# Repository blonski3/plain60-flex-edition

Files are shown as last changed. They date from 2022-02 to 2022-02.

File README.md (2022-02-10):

# Plain60 MX+ALPS Flex Edition rev2.2

Plain60 Flex Edition PCB
This universal 60% PCB is designed to support as little layouts as possible without limiting usability for most users. The reason I did this is because other PCBs made for this form factor usually have so many supported layouts that it could almost qualify as swiss cheese.

It also features a fuse and an ESD protection chip to protect the MCU and other parts of the PCB.

## Features
- Fits in the TGR Unikorn
- Compatible with QMK Firmware and VIA Configurator (if you flash a VIA compatible .hex file)
- Compatible with most universal 60% cases and HHKB/WKL Tofu by KBDfans
- USB type-C
- Optional JST header for connection with daughterboard
- Footprint for optional speaker (AST1109MLTRQ)
- ESD protection and fuse
- No LEDs and no underglow
- Minimal layout support
- ISP header

## Supported layouts
Supported layouts of the Plain60-C

## Building
If you feel like building a few of these PCBs yourself, go to the 'Releases' tab and download the latest gerber files. Order those at your favourite PCB manufacturer, get the components needed (see below) and solder them on! A hot air station is not required but a soldering iron is. Flux is recommended.

## Opening the project
To open the files you will need the latest KiCAD nightly version.

## Bill of materials (BOM)
Amount is per PCB, multiply as needed.

| LCSC part # | Description | Value | Package  | Amount |
| --- | --- | ----- | --- | ---:|
| C128353 | Capacitor | 0.1uF | 0805 | 4 |
| C131056 | Capacitor | 4.7uF | 0805 | 1 |
| C215803 | Capacitor | 1uF | 0805 | 1 |
| C109001 | Diode | | 0805 | 65 |
| C261942 | Fuse | | 0805 | 1 |
| C165948 | Connector | | SMD/THT  | 1 |
| C103904 | Resistor | 10K | 0805 | 2 |
| C212411 | Resistor | 5.1K  | 0805 | 2 |
| C325772 | Resistor | 22 | 0805 | 2 |
| C44854 | MCU | 32U4  | QFP-44 | 1 |
| C7519 | ESD chip | | SOT23-6  | 1 |
| C341521 | Resonator | 16MHz | SMD | 1 |
| C92584 | Switch | | SMD | 1 |
| C160404 | Optional JST  | | SMD | 1 |

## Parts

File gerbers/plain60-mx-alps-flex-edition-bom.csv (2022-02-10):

Comment | Designator | Footprint | JLCPCB Part #（optional）
1u | C1 | C_0805 | C215803
0.1u | C4,C5,C2,C3 | C_0805 | C128353
4.7u | C6 | C_0805 | C131056
D | D73,D72,D71,D67,D63,D59,D58,D57,D56,D53,D51,D50,D27,D42,D18,D25,D41,D36,D31,D40,D37,D32,D34,D21,D26,D22,D24,D43,D38,D35,D48,D54,D44,D62,D39,D20,D28,D33,D23,D55,D52,D19,D10,D14,D9,D13,D11,D15,D17,D16,D12,D7,D3,D5,D8,D6,D4,D74,D49,D46,D29,D1,D47,D2,D61 | D_0805 | C109001
Polyfuse | F1 | R_0805 | C261942
HRO-TYPE-C-31-M-12 | J1 | HRO-TYPE-C-31-M-12 | C165948
ai03_ud | J3 | JST_SH_SM04B-SRSS-TB_1x04-1MP_P1.00mm_Horizontal | C160404
22 | R1,R2 | R_0805 | C413250
5.1k | R4,R3 | R_0805 | C212411
10k | R6,R5 | R_0805 | C103904
SW_PUSH | SW1 | SW_SPST_TL3342 | C92584
ATmega32U4 | U1 | ATMEGA32U4 | C44854
USBLC6-2SC6 | U2 | USBLC6-2SC6 | C7519
XTAL_GND | X1 | Resonator_SMD_muRata_CSTNExxV-3Pin-p1.2 | C341521

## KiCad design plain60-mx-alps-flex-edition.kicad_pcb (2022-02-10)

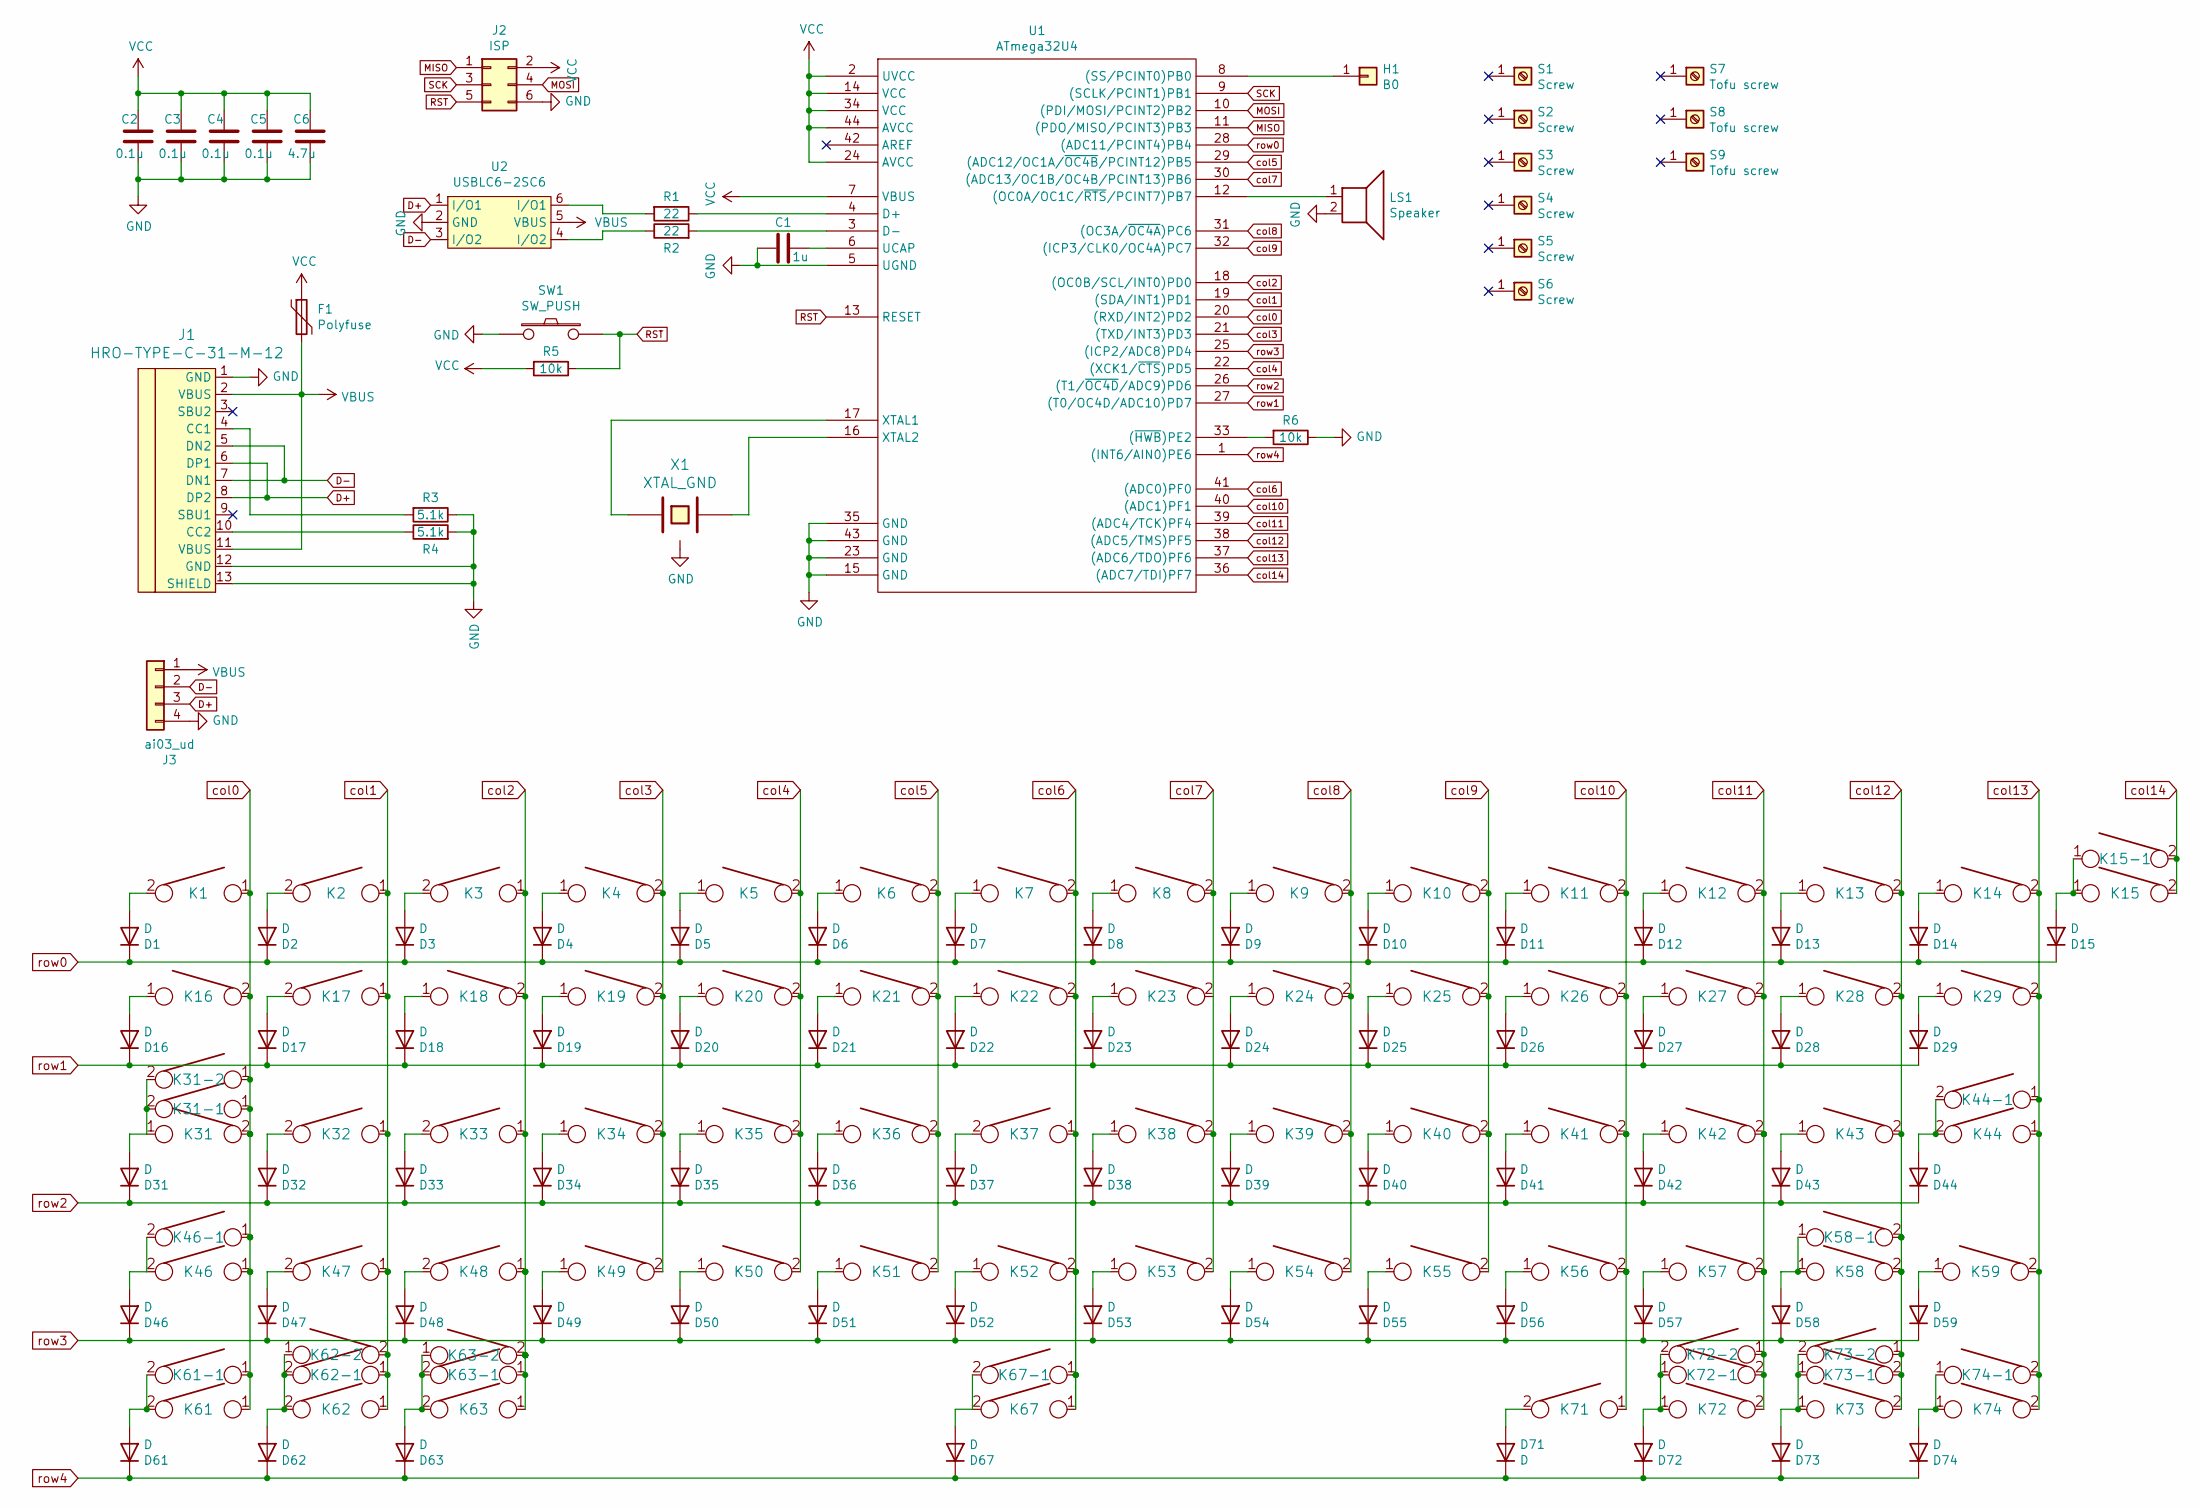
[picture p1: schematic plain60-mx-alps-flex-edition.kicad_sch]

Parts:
C1: 1u; C_0805
C2, C3, C4, C5: 0.1u; C_0805
C6: 4.7u; C_0805
D1, D2, D3, D4, D5, D6, D7, D8, D9, D10, D11, D12, D13, D14, D15, D16, D17, D18, D19, D20, D21, D22, D23, D24, D25, D26, D27, D28, D29, D31, D32, D33, D34, D35, D36, D37, D38, D39, D40, D41, D42, D43, D44, D46, D47, D48, D49, D50, D51, D52, D53, D54, D55, D56, D57, D58, D59, D61, D62, D63, D67, D71, D72, D73, D74: D; D_0805
F1: Polyfuse; R_0805
H1: B0; free_pin
J1: HRO-TYPE-C-31-M-12
J2: ISP; isp_standard
J3: ai03_ud; JST_SH_SM04B-SRSS-TB_1x04-1MP_P1.00mm_Horizontal
K1, K2, K3, K4, K5, K6, K7, K8, K9, K10, K11, K12, K13, K14, K15-1, K17, K18, K19, K20, K21, K22, K23, K24, K25, K26, K27, K28, K32, K33, K34, K35, K36, K37, K38, K39, K40, K41, K42, K47, K48, K49, K50, K51, K52, K53, K54, K55, K56, K57, K59, K62-1, K73-1: KEYSW; MX-1U-NoLED
K15: KEYSW; MX-2U-NoLED
K16, K29, K43, K61-1, K63-1, K72-1, K74-1: KEYSW; MX-1.5U-NoLED
K31, K58-1: KEYSW; MX-1.75U-NoLED
K31-1, K46-1, K61, K62, K63, K71, K72, K73, K74: KEYSW; MX-1.25U-NoLED
K31-2, K63-2, K72-2: KEYSW; ALPS-1.5U
K44, K46: KEYSW; MX-2.25U-NoLED
K44-1: KEYSW; MX-ISO-FLIPPED-ReversedStabilizers
K58: KEYSW; MX-2.75U-NoLED
K62-2, K73-2: KEYSW; ALPS-1.25U
K67: KEYSW; MX-6.25U-ReversedStabilizers-NoLED
K67-1: KEYSW; MX-7U-ReversedStabilizers-NoLED
LS1: Speaker; speaker_AST1109MLTRQ
R1, R2: 22; R_0805
R3, R4: 5.1k; R_0805
R5, R6: 10k; R_0805
S1, S2, S3, S6: Screw; 5.5_5x2.5mm
S4, S5: Screw; 10x5_7x2.5mm
S7, S8, S9: Tofu screw; 5.5_5x2.5mm
SW1: SW_PUSH; SW_SPST_TL3342
U1: ATmega32U4; ATMEGA32U4
U2: USBLC6-2SC6; Farnell 1295310
X1: XTAL_GND; Resonator_SMD_muRata_CSTNExxV-3Pin-p1.2

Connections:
D+: J1.6 (DP1), J1.8 (DP2), J3.3, U2.1 (I/O1)
D-: J1.5 (DN2), J1.7 (DN1), J3.2, U2.3 (I/O2)
GND: C1.2, C2.1, C3.1, C4.1, C5.1, C6.1, J1.1 (GND), J1.12 (GND), J1.13 (SHIELD), J2.6, J3.4, LS1.2, R3.1, R4.2, R6.1, SW1.1, U1.5 (UGND), U1.15 (GND), U1.23 (GND), U1.35 (GND), U1.43 (GND), U2.2 (GND), X1.3
MISO: J2.1, U1.11 ((PDO/MISO/PCINT3)PB3)
MOSI: J2.4, U1.10 ((PDI/MOSI/PCINT2)PB2)
unnamed: C1.1, U1.6 (UCAP)
unnamed: D1.2 (A), K1.2
unnamed: D2.2 (A), K2.2
unnamed: D3.2 (A), K3.2
unnamed: D4.2 (A), K4.1
unnamed: D5.2 (A), K5.1
unnamed: D6.2 (A), K6.1
unnamed: D7.2 (A), K7.1
unnamed: D8.2 (A), K8.1
unnamed: D9.2 (A), K9.1
unnamed: D10.2 (A), K10.1
unnamed: D11.2 (A), K11.1
unnamed: D12.2 (A), K12.1
unnamed: D13.2 (A), K13.1
unnamed: D14.2 (A), K14.1
unnamed: D15.2 (A), K15.1, K15-1.1
unnamed: D16.2 (A), K16.1
unnamed: D17.2 (A), K17.2
unnamed: D18.2 (A), K18.1
unnamed: D19.2 (A), K19.1
unnamed: D20.2 (A), K20.1
unnamed: D21.2 (A), K21.1
unnamed: D22.2 (A), K22.1
unnamed: D23.2 (A), K23.1
unnamed: D24.2 (A), K24.1
unnamed: D25.2 (A), K25.1
unnamed: D26.2 (A), K26.1
unnamed: D27.2 (A), K27.1
unnamed: D28.2 (A), K28.1
unnamed: D29.2 (A), K29.1
unnamed: D31.2 (A), K31.1, K31-1.2, K31-2.2
unnamed: D32.2 (A), K32.2
unnamed: D33.2 (A), K33.2
unnamed: D34.2 (A), K34.1
unnamed: D35.2 (A), K35.1
unnamed: D36.2 (A), K36.1
unnamed: D37.2 (A), K37.2
unnamed: D38.2 (A), K38.1
unnamed: D39.2 (A), K39.1
unnamed: D40.2 (A), K40.1
unnamed: D41.2 (A), K41.1
unnamed: D42.2 (A), K42.1
unnamed: D43.2 (A), K43.1
unnamed: D44.2 (A), K44.2, K44-1.2
unnamed: D47.2 (A), K47.2
unnamed: D48.2 (A), K48.2
unnamed: D49.2 (A), K49.1
unnamed: D50.2 (A), K50.1
unnamed: D51.2 (A), K51.1
unnamed: D52.2 (A), K52.1
unnamed: D53.2 (A), K53.1
unnamed: D54.2 (A), K54.1
unnamed: D55.2 (A), K55.1
unnamed: D56.2 (A), K56.1
unnamed: D57.2 (A), K57.1
unnamed: D58.2 (A), K58.1, K58-1.1
unnamed: D62.2 (A), K62.2, K62-1.2, K62-2.1
unnamed: D63.2 (A), K63.2, K63-1.2, K63-2.1
unnamed: D67.2 (A), K67.2, K67-1.2
unnamed: D71.2 (A), K71.2
unnamed: D72.2 (A), K72.1, K72-1.1, K72-2.2
unnamed: D73.2 (A), K73.1, K73-1.1, K73-2.2
unnamed: D74.2 (A), K74.1, K74-1.1
unnamed: H1.1, U1.8 ((SS/PCINT0)PB0)
unnamed: J1.4 (CC1), R3.2
unnamed: J1.10 (CC2), R4.1
unnamed: D46.2 (A), K46.2, K46-1.2
unnamed: D59.2 (A), K59.1
unnamed: D61.2 (A), K61.2, K61-1.2
unnamed: LS1.1, U1.12 ((OC0A/OC1C/~RTS/PCINT7)PB7)
unnamed: R1.1, U1.4 (D+)
unnamed: R1.2, U2.6 (I/O1)
unnamed: R2.1, U2.4 (I/O2)
unnamed: R2.2, U1.3 (D-)
unnamed: R6.2, U1.33 ((~HWB)PE2)
unnamed: U1.16 (XTAL2), X1.2
unnamed: U1.17 (XTAL1), X1.1
RST: J2.5, R5.1, SW1.2, U1.13 (RESET)
SCK: J2.3, U1.9 ((SCLK/PCINT1)PB1)
VBUS: F1.2, J1.2 (VBUS), J1.11 (VBUS), J3.1, U2.5 (VBUS)
VCC: C2.2, C3.2, C4.2, C5.2, C6.2, F1.1, J2.2, R5.2, U1.2 (UVCC), U1.7 (VBUS), U1.14 (VCC), U1.24 (AVCC), U1.34 (VCC), U1.44 (AVCC)
col0: K1.1, K16.2, K31.2, K31-1.1, K31-2.1, K46.1, K46-1.1, K61.1, K61-1.1, U1.20 ((RXD/INT2)PD2)
col1: K2.1, K17.1, K32.1, K47.1, K62.1, K62-1.1, K62-2.2, U1.19 ((SDA/INT1)PD1)
col2: K3.1, K18.2, K33.1, K48.1, K63.1, K63-1.1, K63-2.2, U1.18 ((OC0B/SCL/INT0)PD0)
col3: K4.2, K19.2, K34.2, K49.2, U1.21 ((TXD/INT3)PD3)
col4: K5.2, K20.2, K35.2, K50.2, U1.22 ((XCK1/~CTS)PD5)
col5: K6.2, K21.2, K36.2, K51.2, U1.29 ((ADC12/OC1A/~OC4B/PCINT12)PB5)
col6: K7.2, K22.2, K37.1, K52.2, K67.1, K67-1.1, U1.41 ((ADC0)PF0)
col7: K8.2, K38.2, K53.2, U1.30 ((ADC13/OC1B/OC4B/PCINT13)PB6)
col8: K9.2, K24.2, K39.2, K54.2, U1.31 ((OC3A/~OC4A)PC6)
col9: K10.2, K25.2, K40.2, K55.2, U1.32 ((ICP3/CLK0/OC4A)PC7)
col10: K11.2, K26.2, K41.2, K56.2, K71.1, U1.40 ((ADC1)PF1)
col11: K12.2, K27.2, K42.2, K57.2, K72.2, K72-1.2, K72-2.1, U1.39 ((ADC4/TCK)PF4)
col12: K13.2, K28.2, K43.2, K58.2, K58-1.2, K73.2, K73-1.2, K73-2.1, U1.38 ((ADC5/TMS)PF5)
col13: K14.2, K29.2, K44.1, K44-1.1, K59.2, K74.2, K74-1.2, U1.37 ((ADC6/TDO)PF6)
col14: K15.2, K15-1.2, U1.36 ((ADC7/TDI)PF7)
row0: D1.1 (K), D2.1 (K), D3.1 (K), D4.1 (K), D5.1 (K), D6.1 (K), D7.1 (K), D8.1 (K), D9.1 (K), D10.1 (K), D11.1 (K), D12.1 (K), D13.1 (K), D14.1 (K), D15.1 (K), U1.28 ((ADC11/PCINT4)PB4)
row1: D16.1 (K), D17.1 (K), D18.1 (K), D19.1 (K), D20.1 (K), D21.1 (K), D22.1 (K), D23.1 (K), D24.1 (K), D25.1 (K), D26.1 (K), D27.1 (K), D28.1 (K), D29.1 (K), U1.27 ((T0/OC4D/ADC10)PD7)
row2: D31.1 (K), D32.1 (K), D33.1 (K), D34.1 (K), D35.1 (K), D36.1 (K), D37.1 (K), D38.1 (K), D39.1 (K), D40.1 (K), D41.1 (K), D42.1 (K), D43.1 (K), D44.1 (K), U1.26 ((T1/~OC4D/ADC9)PD6)
row3: D46.1 (K), D47.1 (K), D48.1 (K), D49.1 (K), D50.1 (K), D51.1 (K), D52.1 (K), D53.1 (K), D54.1 (K), D55.1 (K), D56.1 (K), D57.1 (K), D58.1 (K), D59.1 (K), U1.25 ((ICP2/ADC8)PD4)
row4: D61.1 (K), D62.1 (K), D63.1 (K), D67.1 (K), D71.1 (K), D72.1 (K), D73.1 (K), D74.1 (K), U1.1 ((INT6/AIN0)PE6)

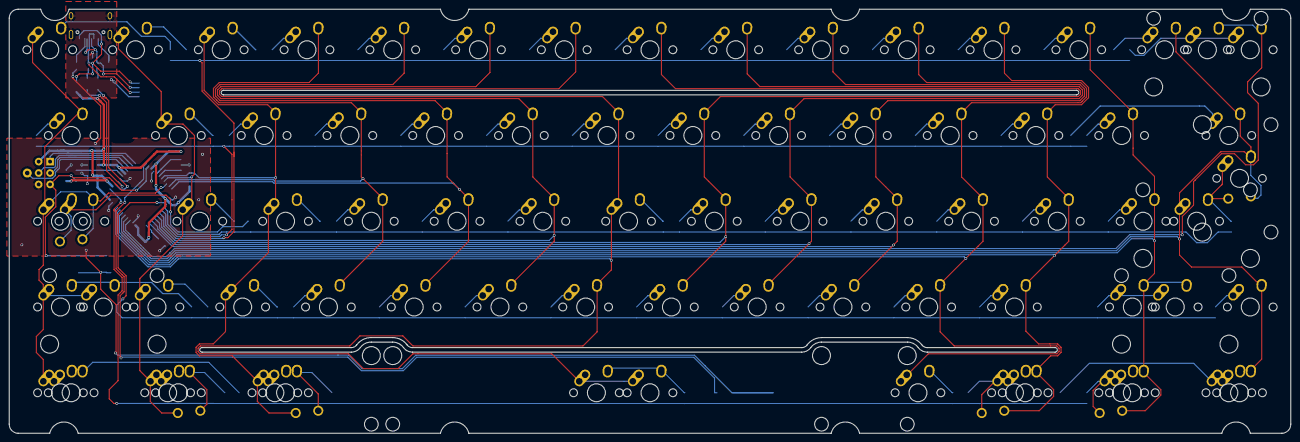
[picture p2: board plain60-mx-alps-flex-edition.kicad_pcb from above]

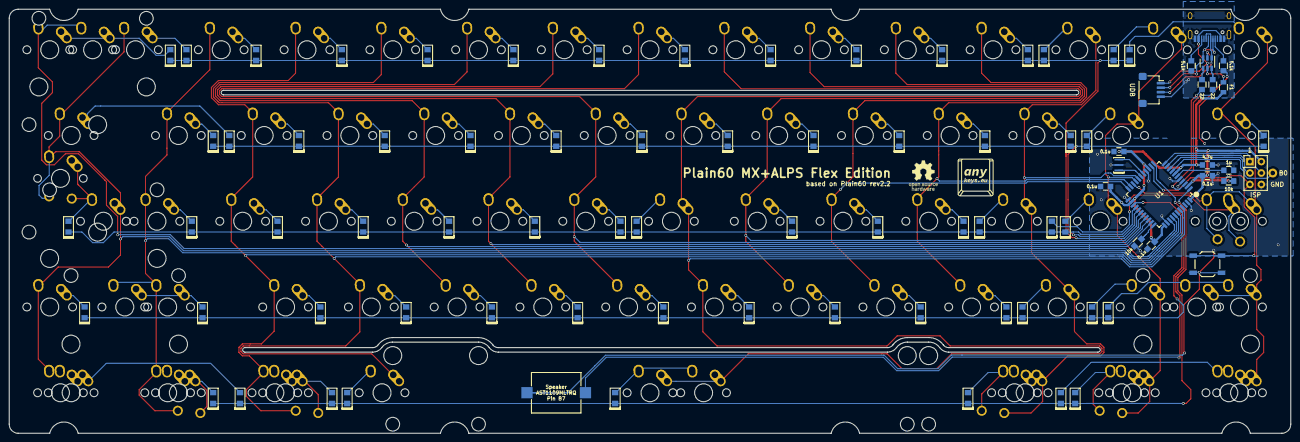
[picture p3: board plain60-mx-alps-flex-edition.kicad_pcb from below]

Board: 2 copper layers, 284.7 x 94.2 mm, 178 parts (87 on the bottom side), 106 nets.

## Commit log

2022-02-10 Footprints from plain60-alps-flex-edition
2022-02-10 Footprints exported from PCB files
2022-02-10 Change footprints to MX+ALPS
    [plain60-flex-edition.kicad_pcb, plain60-flex-edition.kicad_sch]
2022-02-10 Add AEK support
    [plain60-flex-edition.kicad_pcb, plain60-flex-edition.kicad_sch]
2022-02-10 JLC files
    [plain60-mx-alps-flex-edition-bom.csv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]
